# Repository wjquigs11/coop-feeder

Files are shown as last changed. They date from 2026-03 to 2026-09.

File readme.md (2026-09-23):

# Load Cell Chicken Coop Feeder Gauge

This project uses an ESP32 microcontroller connected to a load cell via an HX711 ADC to monitor the weight of a chicken feeder. The system provides a web interface with a gauge visualization showing the current feed level as a percentage. The project includes WiFi connectivity with a captive portal for easy setup, OTA updates, and a WebSerial interface for debugging and configuration.

Hanging the feeder in the coop helps to discourage pests (although rats can certainly jump up onto the feeder if they're really motivated).

# **IMPORTANT:** 

Do not build the react app on Dropbox. Compiling changes hundreds of files and Dropbox cannot sync and builds often fail. Check out the repo on a local drive for compilation.

## What It Does

- **Load Cell Monitoring**: Measures the weight of the chicken feeder using an HX711 load cell amplifier
- **Web Interface**: Displays feed level as a percentage on a gauge visualization
- **WiFi Connectivity**: Connects to your home network with easy setup via NetWizard captive portal
- **WebSerial Interface**: Provides command-line access for configuration and debugging
- **OTA Updates**: Supports over-the-air firmware updates via ElegantOTA
- **SPIFFS Storage**: Stores configuration and logs in flash memory
- **Double Reset Detection**: Reset WiFi configuration by pressing reset button twice within 10 seconds

## Hardware

- ESP32 development board (ESP32-DOIT-DEVKIT-V1) - sometimes a screw terminal board is easiest to use [Amazon Link](https://www.amazon.com/Development-Bluetooth-Microcontroller-ESP-WROOM-32-Breakout/dp/B0C8DBN29X/ref=sr_1_6)
- [HX711 load cell amplifier](https://www.sparkfun.com/products/13879)
- [Load cell (weight sensor)](https://www.sparkfun.com/products/14151)
- Power supply
- Mounting hardware for the load cell

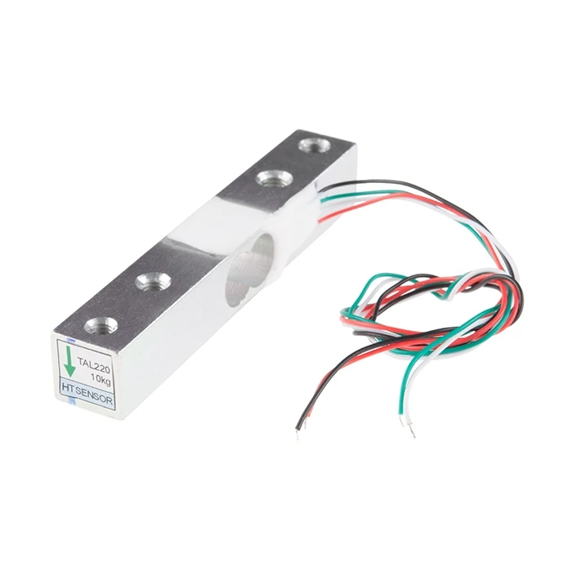
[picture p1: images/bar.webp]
bar load cell

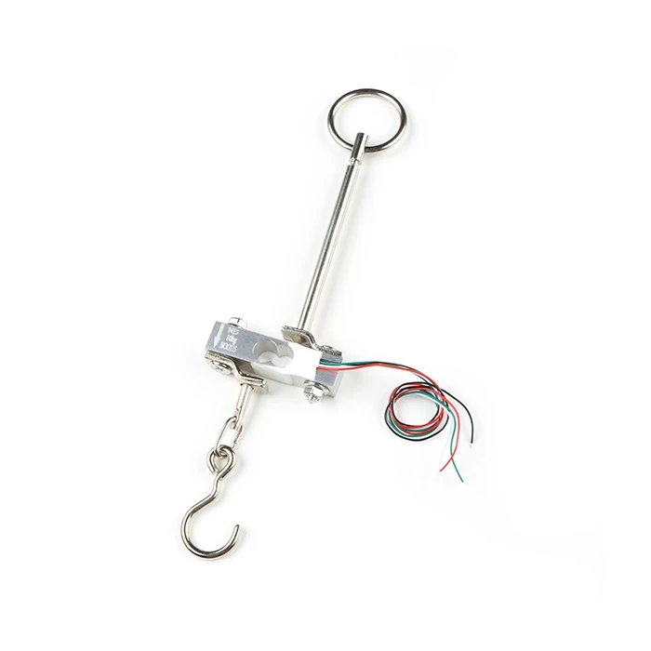
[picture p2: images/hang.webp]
hanging load cell


## Wiring

- HX711 DOUT pin → ESP32 GPIO 27
- HX711 SCK pin → ESP32 GPIO 14
- Connect load cell to HX711. [Sparkfun](https://learn.sparkfun.com/tutorials/load-cell-amplifier-hx711-breakout-hookup-guide) has a good guide.

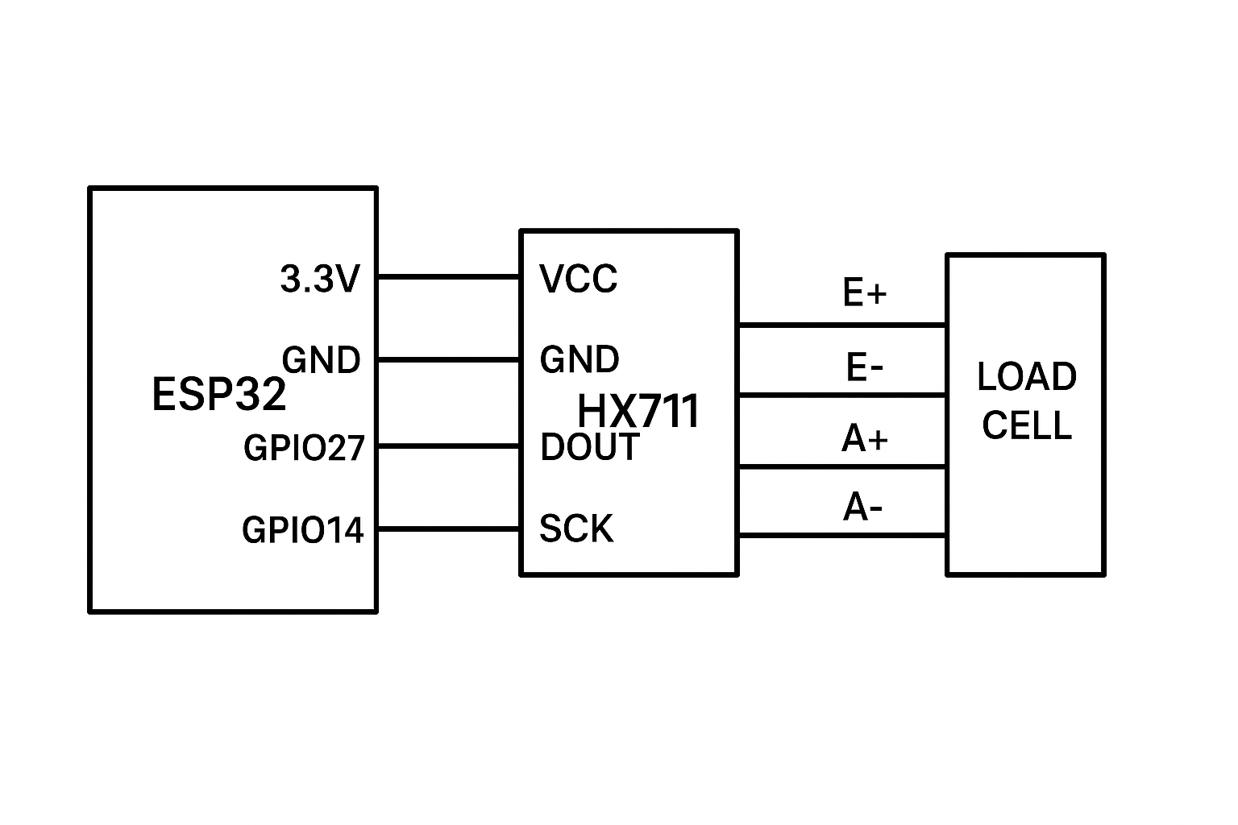
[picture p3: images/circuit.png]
circuit drawing


## Installation

1. Clone this repository
2. Open the project in [PlatformIO](https://platformio.org/)
3. Build and upload the filesystem image:
   - PlatformIO → Build Filesystem Image
   - PlatformIO → Upload Filesystem Image
     I recommend the "Pro" version of WebSerial, but if you are using the free version, modify platformio.ini to match. You will also need to change header file references.
4. Build and upload the firmware to your ESP32

- Note that the executable is fairly large; almost 4MB, so you may want to comment out definitions in platformio.ini if you don't need e.g. WebSerial. ElegantOTA is commented out but available if you modify and want to update the code without many trips to the coop :-)

## First-Time Setup

1. After the first upload, the ESP32 will start in AP mode with a NetWizard captive portal
2. Connect to the "COOPFEEDER" WiFi network from your phone or computer
3. Follow the on-screen instructions to connect the device to your home WiFi network
4. The device will restart and connect to your WiFi network
5. Place an empty feeder on the load cell
6. Calibrate the load cell with the empty feeder
   - Browse to `http://coopfeeder.local/config?empty` or
   - Use WebSerial at `http://coopfeeder.local/webserial` and enter the command `empty`
7. Fill the feeder to maximum capacity
   - Browse to `http://coopfeeder.local/config?full` or
   - Use WebSerial and enter the command `full`
     Your specific values will be saved in flash on the ESP32

  I had a bar load cell from another project. I fixed one end to a piece of flat fiberglass bar (and old sail batten), and clamped it in the coop. The feeder hangs from a split ring on the other end of the bar. The hanging-style load cell is probably easier to install.

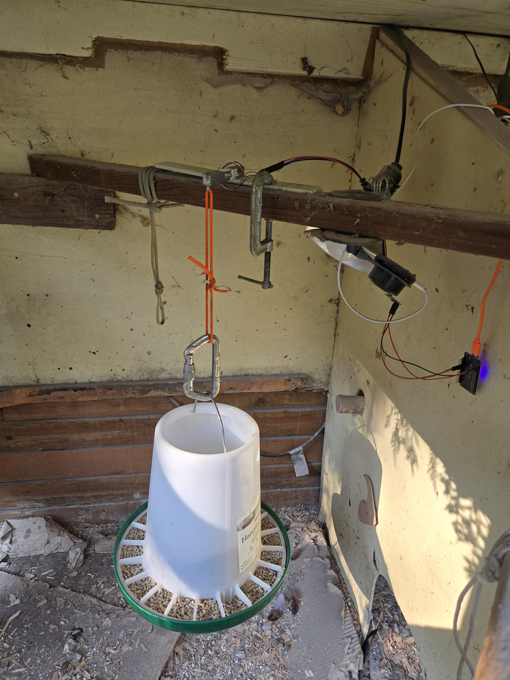
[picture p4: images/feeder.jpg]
load cell


## Web Interface

Access the web interface by navigating to `http://coopfeeder.local/` in your browser.

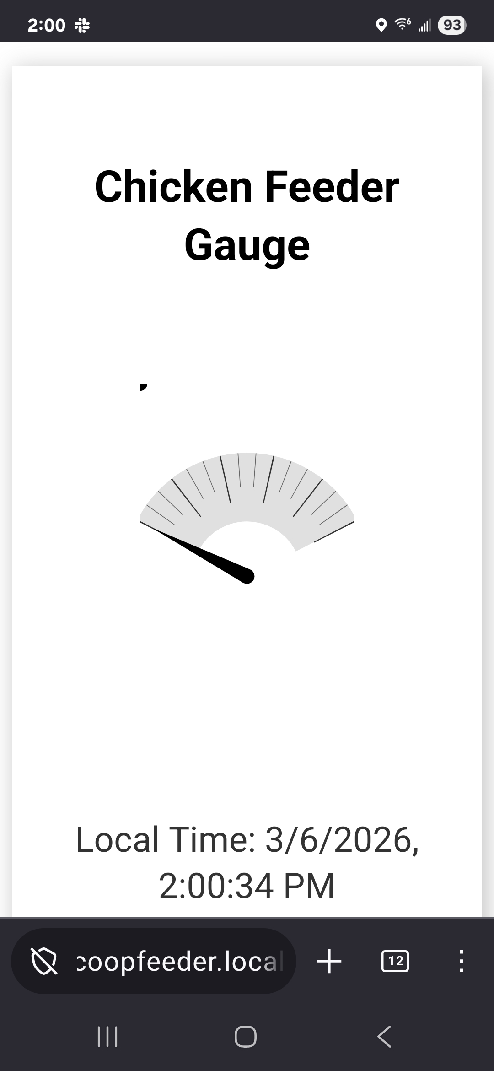
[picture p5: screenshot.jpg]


## Configuration

You can configure the device using the WebSerial interface at `http://coopfeeder.local/webserial` or by using URL parameters:

### WebSerial Commands

- `empty` - Calibrate the load cell with an empty feeder
  'empty ?' shows current raw value for empty feeder
  'empty <number></number>' sets raw value
- `full` - Calibrate the load cell with a full feeder, 'full ?' and 'full <number></number>' work same as empty.
- `hostname [name]` - Change the device hostname
- `timer [seconds]` - Change the web page update interval in seconds
- `ls` - List files in SPIFFS
- `status` - Show device status
- `wifi` - Show WiFi information
- `restart` - Restart the device
- `format` - Format the SPIFFS filesystem
- `conslog` - Restart the console log
- `log [on/off]` - Enable/disable serial logging
- `note [text]` - Add a note to the log
- `?` - Show available commands

### URL Configuration

- `http://coopfeeder.local/config?hostname=newname` - Change hostname
- `http://coopfeeder.local/config?webtimer=1000` - Change update interval (in milliseconds)
- `http://coopfeeder.local/config?empty` - Calibrate with empty feeder
- `http://coopfeeder.local/config?full` - Calibrate with full feeder

## API Endpoints

- `/readings` - Get current sensor readings as JSON
- `/weight` - Get current weight value as plain text
- `/host` - Get hostname and MAC address
- `/console.log` - Access the console log file

## Resetting WiFi Configuration

To reset the WiFi configuration and return to the captive portal setup:

1. Press the reset button on the ESP32
2. Within 10 seconds, press the reset button again
3. The device will clear WiFi settings and restart in AP mode

## Logs

A console log is stored on the SPIFFS filesystem and can be accessed via `http://coopfeeder.local/console.log`. This is mainly for debugging purposes.

## Resources

- [ESP32 Documentation](https://docs.espressif.com/projects/esp-idf/en/latest/esp32/)
- [HX711 Datasheet](https://cdn.sparkfun.com/datasheets/Sensors/ForceFlex/hx711_english.pdf)
- [PlatformIO Documentation](https://docs.platformio.org/)
- [SPIFFS Documentation](https://arduino-esp8266.readthedocs.io/en/latest/filesystem.html)

## Credits

This project depends heavily on the excellent utility libraries from [Ayush Sharma](https://github.com/ayushsharma82), as well as the lightweight Javascript gauge library from [Bernii](https://bernii.github.io/gauge.js/).

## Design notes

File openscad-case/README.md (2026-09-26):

# Hanging load-cell case with slide-in electronics

The load cell and 18650 holder stand vertically beside one another. Three paired L-shaped PCB channels are rotated 90 degrees onto the left side wall. The board planes are perpendicular to the back and lid, with populated faces toward the left wall. They grip PCB edges without mounting holes. The upper two M4 holes fix the sensor; the lower end remains free, with an M4 screw eye and a wire running over the fixed plastic guide to the bottom exit.

## Size and references

Housing: **79 mm wide × 180 mm high × 51 mm deep**, excluding screw heads and hanging loop. Overall height with loop: **205 mm**. The hanging loop is centered on the upper end of the box, at X=-7.5 and Z=24 mm (midway between back and lid). Its hole remains 10 mm diameter. The housing and lid have an oblong oval outline with 39.5 mm-radius semicircular ends; the four lid screws sit in the rounded ends. The electrical-lead slot in the side wall has been removed.

| Component | Envelope used (mm) | Source |
|---|---|---|
| Load cell | 75 × 12.7 × 12.7 | Original drawing and load-cell.png |
| Installed 18650 + holder | 78 × 21 × 21 | Assumed per user instruction, allowing holder/contact space around nominal 18 × 65 cell |
| HX711 | 33 × 20 × 6 | hx711.png footprint; assumed height |
| XIAO | 21 × 17.8 × 6 | https://wiki.seeedstudio.com/Seeeduino-XIAO/ footprint; assumed height |
| Charger | 18.2 × 12.3 × 6 | charger.png footprint including USB projection; assumed height |

PCB references assume 1.6 mm substrate thickness, 6 mm total populated height, no pin headers, and a 1.2 mm clear strip along the two retained edges. These edge/component clearances are not dimensioned in the photos: verify them on actual boards, especially soldered wires and the charger's connector. PCB envelopes depict a substrate plus an inset populated region; they are not detailed component models.

Converted AVIF copies are saved as `battery-holder.png`, `hx711.png`, `charger.png`, and `load-cell.png`. Originals remain in the folder. The holder photo has no dimension labels. Unusually long/protected cells may require a larger holder envelope.

## Printed files

- `load_cell_case.scad`: self-contained main source.
- `electronics_fit.scad`: final open-case component preview.
- `print_parts/base.stl`: case with channels, battery cradle, hanging loop, and wire guide.
- `print_parts/lid.stl`: removable lid.
The lid now has three integral board-retention stops. Separate retainers and M2 screws are no longer required.

Set `part` to `"open"` to inspect the layout. Other selections are `"assembly"`, `"exploded"`, `"base"`, `"lid"`, `"print_layout"`, `"mechanism"`, and `"cutaway"`. Assembly displays rotate upright; individual print parts are bed-oriented. Green = HX711, blue = XIAO, orange board = charger, purple = battery/holder.

## Slide channels

Each board has paired L-ledges, retaining lips, and a closed end near the back. Remove the lid and slide each board **from the lid opening toward the back**, along -Z in the part coordinates. The boards are ordered bottom to top: HX711, XIAO, charger. Their long dimensions now extend into the case depth.

- Slot height: 2.0 mm for a 1.6 mm board, with 0.2 mm clearance on either face.
- Edge fit: 0.3 mm per retained edge.
- Lip overlap: 0.8 mm onto each edge.
- Integral lid stops allow approximately 0.8 mm withdrawal before retaining the boards.
- Change `pcb_thickness` and `slot_clearance` to match actual board thickness/printer fit.

The channels attach directly to the side wall with ribs outside the PCB envelopes. No screws or adhesive touch the boards. Closing the lid installs all three retention stops; removing it releases the boards for withdrawal.

Flexible direct-soldered leads need enough slack to slide boards out. Route wires clear of the rails and lid stops. Access USB with the lid off and a board withdrawn if necessary; external USB openings are not yet defined from measured connectors and plugs. The former open side slot is closed.

## Other hardware and assembly

- Two M4×10 socket-head screws for the fixed upper sensor end, nominally 6.2 mm engagement. Verify thread depth.
- One purchased M4 eye for the upper hole of the lower pair. Reference: 8 mm outside eye diameter, 5 mm opening, 2.5 mm eye thickness, 4 mm nominal thread engagement.
- Four M3×50 socket-head screws and four M3 nuts for the lid.
- Two small cable ties for the battery holder through the rear slots at Y=12 and Y=60.

The raised battery bed and side rails locate the holder. The load cell mounts at X=-12, with inferred hole positions Y=5.5, 15.5, 59.5, and 69.5. Part axes: X across, Y upward when hanging, Z outward from the back. Confirm the inferred 5.5 mm end margin on the sensor.

Print the case back-down with supports under the curved wire guide and the relocated hanging loop, which now starts 21 mm above the print bed. Inspect the side-channel overhangs in the slicer and keep support material out of the 2 mm grooves. Print the lid exterior-down with its three retention stops pointing upward. PETG and 4–5 walls are prototype starting settings. Clear grooves and smooth the wire-contact surface before assembly.

## Validation and limits

OpenSCAD MCP mesh checks found single watertight, manifold solids for the case and lid. All 21 assembly-pair checks for the revised oval base, lid, battery, sensor, and three boards passed, with 0.8 mm between each board and its lid stop. Earlier sampled sliding-motion checks passed for all three PCBs with the lid removed, against the case, sensor, and battery; that motion sweep has not been repeated for the oval revision. Minimum modeled groove clearance was 0.2 mm. Printed fit still needs checking.

The battery envelope clears the sensor by 9.65 mm. The components retain free space above and around the sensor; the guide remains 6 mm from the sensor. Loaded deflection, actual wires, knots/crimps, plugs, solder joints and printed strength are not validated by these envelope checks.

The fixed guide takes some of the external load; friction and wire bending can cause hysteresis. Calibrate the complete hanging assembly with its actual wire. No overload stop, environmental seal, or load rating is claimed.

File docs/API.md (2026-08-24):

# Coop Feeder HTTP API

This document describes the HTTP endpoints exposed by the coop feeder's
ESP32 web server that an external client (for example a phone app) can use to
read feeder state and change configuration. It is intended for clients that are
not the built-in browser UI.

## Base URL

The device serves HTTP on port `80`. Reach it by IP address or by mDNS
hostname:

```
http://<device-ip>/
http://coopfeeder.local/          # default mDNS name (hostname is configurable)
```

- The mDNS name is derived from the configured hostname (see `/config`), lower
  cased and sanitized to `a-z`, `0-9` and `-`. The default hostname is
  `coopfeederBETA`.
- In AP (access point) mode the device is reachable at its soft-AP IP instead.

## CORS

`GET` endpoints send permissive CORS headers (`Access-Control-Allow-Origin: *`),
and `OPTIONS` preflight requests are answered with `204`. A native phone app
making direct HTTP calls does not need CORS, but a browser-based or hybrid app
will work cross-origin.

---

## Getting feeder state

### GET `/readings`

Primary endpoint for reading current feeder state. Returns the full state
object as JSON.

**Response** `200 application/json`

```json
{
  "loadcell": "72",
  "units": "%",
  "lastUpdate": "1740000000000"
}
```

| Field | Type | Description |
|---|---|---|
| `loadcell` | string (integer)  | Current feed level, `0`–`100`. Mapped from the raw load cell reading between the empty and full calibration offsets. |
| `units` | string | Unit for `loadcell`. Currently `"%"`. |
| `lastUpdate` | string (integer)  | Timestamp of the last reading, in **milliseconds since the Unix epoch**. See note below. |

Notes:
- All values are serialized as JSON **strings**, not numbers. Parse them
  client-side (e.g. `parseInt`).
- Fields only appear once the device has taken at least one reading. Before the
  first reading the object may be empty (`{}`).
- `lastUpdate` is only a true Unix timestamp if a client has posted the current
  time via `POST /browsertime` (see below). The ESP32 has no real-time clock, so
  until then it falls back to the device uptime (`millis()`), which is **not** a
  wall-clock time.

### GET `/weight`

Lightweight endpoint returning just the current feed level as plain text.

**Response** `200 text/plain`

```
72
```

The value is the same `loadcell` figure (`0`–`100`) returned by `/readings`,
without units or timestamp. Useful for a quick poll when you only need the level.

### GET `/host`

Returns device identity information as human-readable plain text (not JSON).

**Response** `200 text/plain`

```
hostname: coopfeederBETA, ESP local MAC addr: AA:BB:CC:DD:EE:FF
```

Contains the current hostname and the ESP32's Wi-Fi MAC address. Handy for
device discovery / identification. The format is a plain string, so parse it
loosely.

---

## Live updates (Server-Sent Events)

### GET `/events`

A Server-Sent Events (SSE) stream. Instead of polling `/readings`, a client can
subscribe once and receive pushes whenever the device takes a new reading.

- Event name: `new_readings`
- Event data: the same JSON payload as `GET /readings`
- On connect, the device immediately sends one `new_readings` event so the
  client is populated right away.
- The push cadence is governed by the device's timer delay (see the `webtimer`
  parameter of `/config`).

Example (browser `EventSource`):

```js
const es = new EventSource("http://coopfeeder.local/events");
es.addEventListener("new_readings", (e) => {
  const state = JSON.parse(e.data);
  console.log(state.loadcell, state.units, state.lastUpdate);
});
```

For a native phone app, use any SSE-capable HTTP client, or fall back to polling
`/readings` on an interval if SSE is inconvenient.

---

## Configuration and calibration

### GET `/config`

Changes device settings. Despite modifying state, it uses `GET` with query
parameters. Send exactly one parameter per request; the first recognized one is
applied. Returns a plain-text confirmation message.

**Response** `200 text/plain` (e.g. `"change web timer to 2000"`, or `"none"`
if no recognized parameter was supplied).

| Parameter  | Example | Effect |
|---|---|---|
| `hostname` | `/config?hostname=henhouse` | Sets the device hostname (also affects the mDNS name). Persisted to flash. |
| `webtimer` | `/config?webtimer=2000` | Sets the reading/update interval in **milliseconds**. Clamped to `0`–`10000`; `<0` resets to the default (`1000`). Persisted. |
| `empty` | `/config?empty=1` | Runs the "empty feeder" calibration (captures the current raw load cell reading as the empty offset). Persisted. |
| `full` | `/config?full=1` | Runs the "full feeder" calibration (averages several raw readings as the full offset). Persisted. |

The `empty` / `full` parameter values are ignored — only presence matters.
Confirmation messages include the resulting offset values, for example
`"empty calibration successful, empty raw offset is 12345"`.

### POST `/browsertime`

Supplies the device with a wall-clock time reference so that `lastUpdate` in
`/readings` becomes a real Unix timestamp. The ESP32 has no RTC, so a client
should send this once after connecting (and periodically if desired).

**Request body** `application/json`

```json
{
  "localTime": "2026-08-24T10:00:00",
  "timezone": "America/New_York",
  "offset": -240,
  "timestamp": 1740000000000
}
```

| Field | Type | Description |
|---|---|---|
| `timestamp` | number | Current time in **milliseconds since the Unix epoch**. This is the value the device actually uses as its clock base. |
| `localTime` | string | Human-readable local time (logged only). |
| `timezone`  | string | IANA timezone name (logged only). |
| `offset` | number | UTC offset in minutes (logged only). |

**Response** `200 text/plain` — body `"Time received"`.

Only `timestamp` affects behavior; the other fields are logged for diagnostics.

---

## Endpoint summary

| Method | Path | Response type | Purpose |
|---|---|---|---|
| GET | `/readings` | `application/json` | Full feeder state (level, units, time) |
| GET | `/weight` | `text/plain` | Current feed level only (`0`–`100`) |
| GET | `/host` | `text/plain` | Hostname + MAC address |
| GET | `/events` | SSE stream | Push updates (`new_readings` events) |
| GET | `/config` | `text/plain` | Change hostname / timer / run calibration |
| POST | `/browsertime` | `text/plain` | Provide a wall-clock time reference |

## Recommended client flow

1. Discover the device (mDNS `coopfeeder.local` or a known IP).
2. Optionally `GET /host` to confirm identity (MAC address).
3. `POST /browsertime` with the current epoch milliseconds so `lastUpdate`
   reflects real time.
4. Either subscribe to `GET /events` for live `new_readings`, or poll
   `GET /readings` (or `GET /weight`) on an interval.
5. Use `GET /config` as needed to adjust the update interval or run calibration.

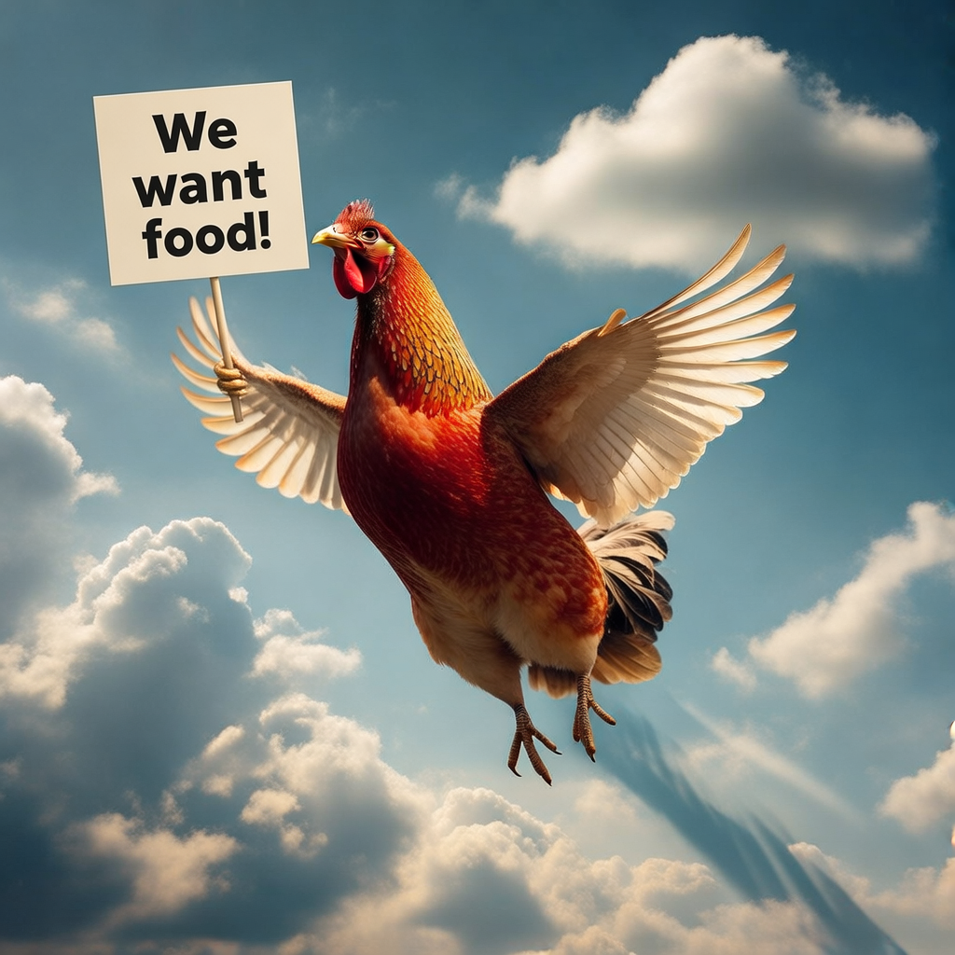
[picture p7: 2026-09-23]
react-app/assets/images/superchicken.png

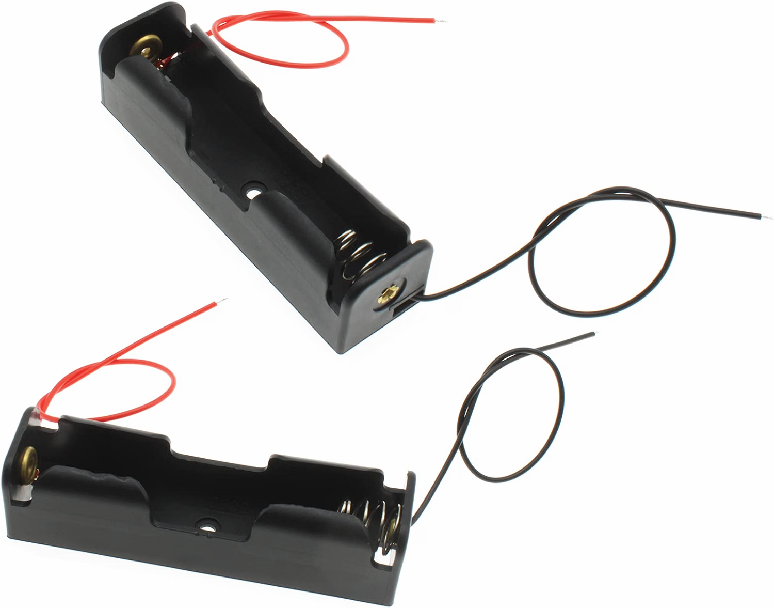
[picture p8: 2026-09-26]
openscad-case/battery-holder.png

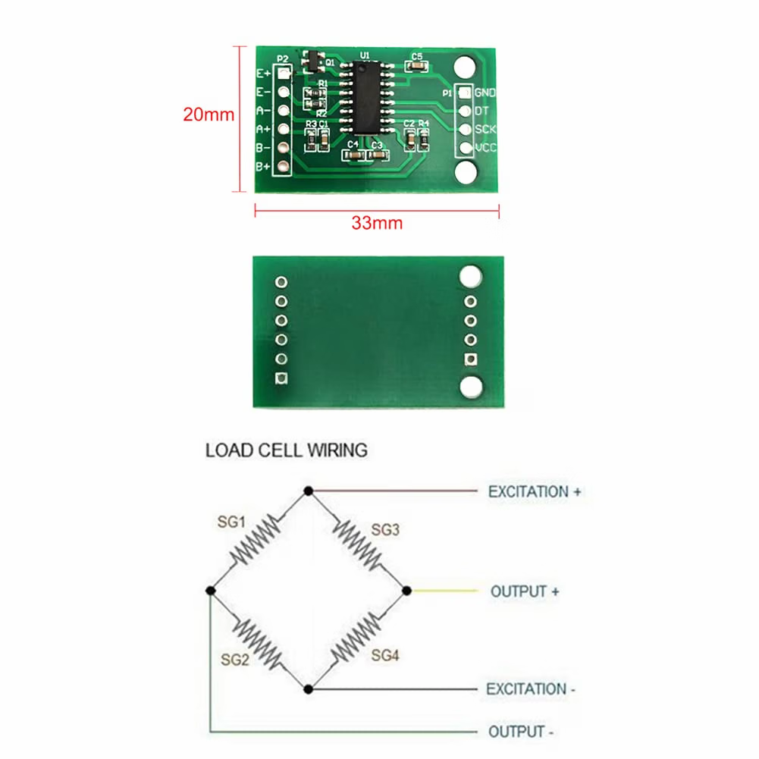
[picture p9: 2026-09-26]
openscad-case/hx711.png

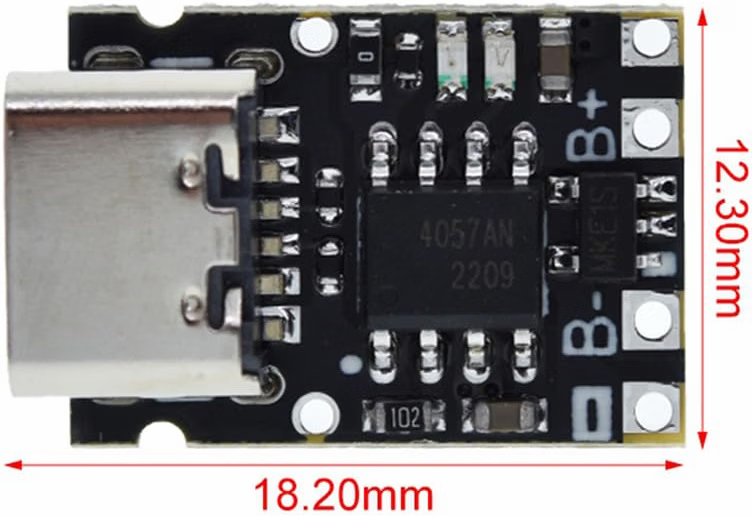
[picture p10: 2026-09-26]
openscad-case/charger.png

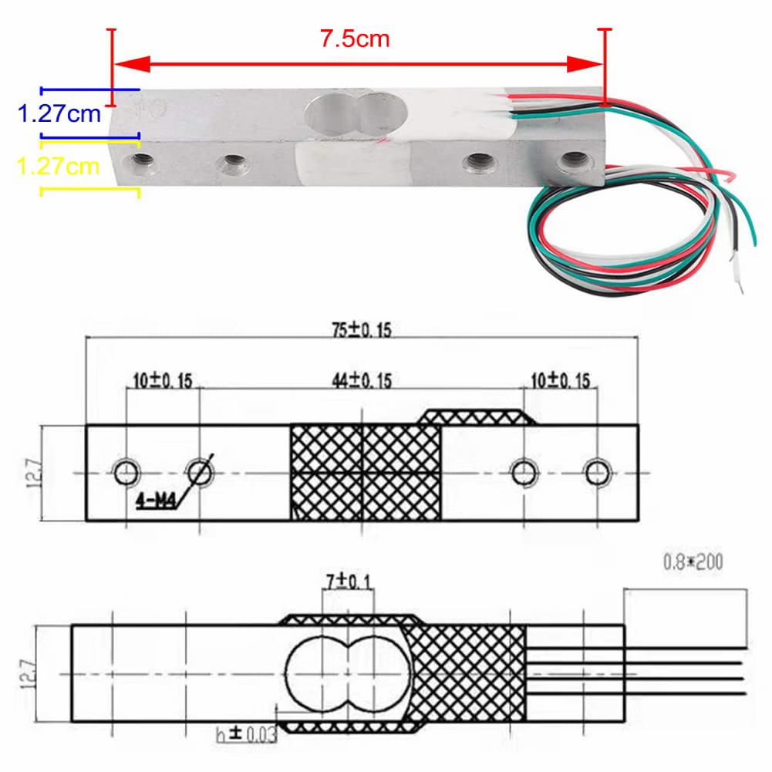
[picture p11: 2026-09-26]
openscad-case/load-cell.png

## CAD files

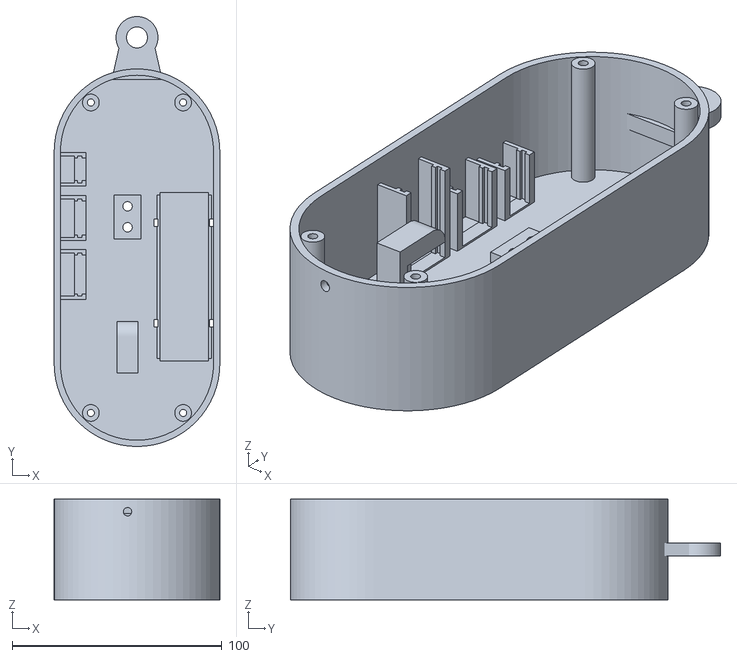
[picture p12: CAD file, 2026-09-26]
openscad-case/print_parts/base.stl
79.0 x 205.0 x 48.0

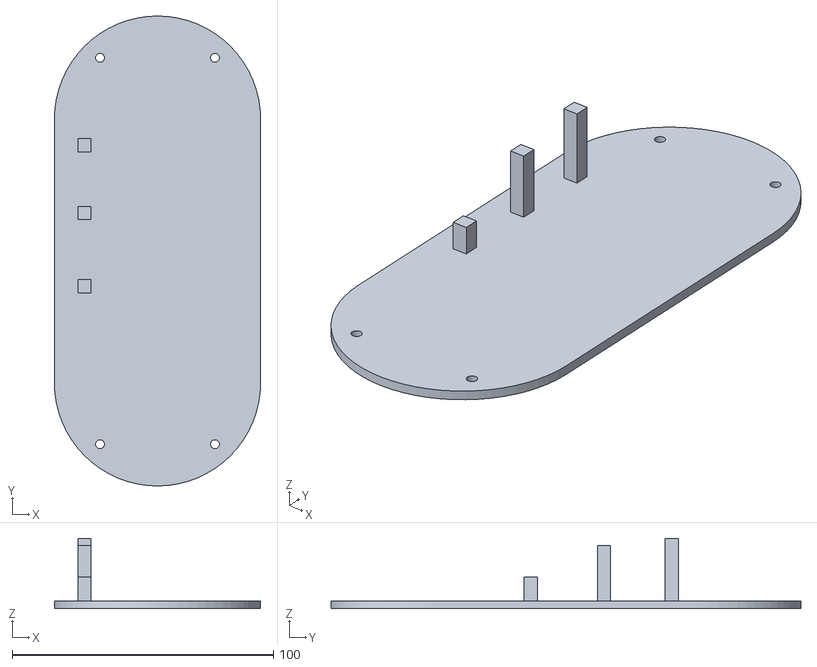
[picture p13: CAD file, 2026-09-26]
openscad-case/print_parts/lid.stl
79.0 x 180.0 x 27.0

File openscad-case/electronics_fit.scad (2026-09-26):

// Final enlarged case, with vertical battery alongside the sensor.
// Component envelopes are defined in load_cell_case.scad.
// Purple: assumed 78 x 21 x 21 holder/battery; green: HX711;
// blue: XIAO; orange: charger. All PCB heights assumed 6 mm.
use <load_cell_case.scad>
rotate([90,0,0]) open_case();

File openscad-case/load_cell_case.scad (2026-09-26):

// Vertical hanging case, revised from case.jpg. Units mm.
// Print coordinates: X across case, Y up when hanging, Z out from back.
// Sensor upper end is fixed. Hole axes are Z; sketch is a side view.
part="assembly"; // assembly, open, exploded, base, lid, print_layout, mechanism, cutaway
show_reference=true;
show_electronics=true;
$fn=64;
cell_l=75; cell_w=12.7; cell_h=12.7;
cell_z=8; holes_y=[69.5,59.5,15.5,5.5];
case_left=-47; case_right=32; case_w=case_right-case_left;
case_mid=(case_left+case_right)/2;
cell_x=case_mid; // load-cell holes and wire diverter centered left/right in case
bottom_y=-45; top_y=135; case_depth=38; // thinned 10mm in Z (was 48)
wall=3; floor_h=4; lid_h=3;
// Sealing rim: thicken the perimeter wall to rim_wall over the top rim_h of depth,
// and cut a gasket groove into the top mating face.
rim_wall=8; rim_h=8;              // thickened wall and its depth band below the top face
groove_off=3; groove_w=3; groove_d=3; // groove: 3mm from outer edge, 3mm wide, 3mm deep
wire_d=1.6; wire_hole_d=4;
guide_r=7.2; guide_y=7.5; guide_z=24; // strut thinned 10mm in Z with the case (was 34)
wire_r=guide_r+wire_d/2;
guide_w=10; // guide body width along X
guide_flange_t=1.5; // side flange thickness (X)
guide_flange_h=wire_d+1.5; // flange rise above wire crown (Z)
eye_od=8; eye_id=5; eye_z=27; eye_y=15.5;
// Screw posts pulled inward so the M3 holes clear the gasket groove by ~2mm.
screw_dx=20.15; screw_iy=17.58; // X half-spread from center; Y inset from each end
screws=[for(y=[bottom_y+screw_iy,top_y-screw_iy],x=[case_mid-screw_dx,case_mid+screw_dx]) [x,y]];
battery_l=78; battery_w=21; battery_h=21; // Assumed holder + installed cell.
battery_pos=[7.8,-3,6]; // centered in pocket: left rail inner face x=7.6, case inner wall x=29, 0.4mm clearance
pcb_h=6; // Total populated height; direct solder, no pin headers.
pcb_z=32; pcb_thickness=1.6; slot_clearance=0.4;
hx_pos=[-42,27,pcb_z]; hx_size=[25,16,pcb_h]; // board 24mm deep + 1mm clearance
xiao_pos=[-42,55,pcb_z]; xiao_size=[21,17.8,pcb_h];
charger_pos=[-42,81,pcb_z]; charger_size=[18.2,12.3,pcb_h];
boards=[[hx_pos,hx_size],[xiao_pos,xiao_size],[charger_pos,charger_size]];
rail_seat=pcb_z-slot_clearance/2; rail_bottom=rail_seat-2;
rail_lip=pcb_z+pcb_thickness+slot_clearance/2; rail_top=rail_lip+1.6;
eps=0.02;
assert(wire_d<wire_hole_d,"Wire must clear exit");
assert(guide_z+wire_r+wire_d/2<case_depth,"Wire must clear lid");
module rounded_box(w,h,d,r=3) {
 linear_extrude(d) hull() for(x=[r,w-r],y=[r,h-r]) translate([x,y]) circle(r=r);
}
module case_outline(inset=0) {
 // Oblong oval: semicircular ends and straight sides preserve the electronics bay.
 translate([case_mid,0]) hull()
  for(y=[bottom_y+case_w/2,top_y-case_w/2])
   translate([0,y]) circle(r=case_w/2-inset);
}
module yz_extrude(w) {
 // child 2D coordinates [Y,Z], extruded along X
 multmatrix([[0,0,1,-w/2],[1,0,0,0],[0,1,0,0],[0,0,0,1]]) linear_extrude(w) children();
}
module guide_local() {
 // Integral fixed shoe: quarter-circle crown, vertical stem, and back attachment.
 yz_extrude(guide_w) union() {
  translate([-10,floor_h-eps]) square([4,guide_z+guide_r-floor_h+eps]);
  translate([-9,guide_z]) square([guide_y+9,guide_r]);
  translate([guide_y,guide_z]) intersection() {
   circle(r=guide_r);
   square([guide_r,guide_r]);
  }
 }
 // Side flanges: raised walls on both X faces to keep the wire from slipping off
 // the crown sideways. Span the crown in Y and rise in Z past the wire.
 for(sx=[-1,1])
  translate([sx*(guide_w/2)+(sx<0?-guide_flange_t:0),-9,guide_z])
   cube([guide_flange_t,guide_y+9+guide_r,wire_r+guide_flange_h]);
}
module guide() { translate([cell_x,0,0]) guide_local(); }
module hanger() {
 // Centered across the box and halfway between back and lid on upper end.
 translate([0,0,case_depth/2-3]) linear_extrude(6) difference() {
  union() {
   polygon([[case_mid-12,top_y-5],[case_mid+12,top_y-5],[case_mid+7,top_y+17],[case_mid-7,top_y+17]]);
   translate([case_mid,top_y+15]) circle(d=20);
  }
  translate([case_mid,top_y+15]) circle(d=10);
 }
}
module base() {
 difference() {
  union() {
   difference() {
    linear_extrude(case_depth) case_outline();
    translate([0,0,floor_h])
     linear_extrude(case_depth+eps) case_outline(wall);
   }
   // Sealing rim: thicken the perimeter wall from wall to rim_wall over the top rim_h,
   // added inward (outer footprint unchanged) to carry the gasket groove.
   translate([0,0,case_depth-rim_h]) linear_extrude(rim_h+eps) difference() {
    case_outline(wall);
    case_outline(rim_wall);
   }
   // Pedestal touches only upper 21 mm of beam.
   translate([cell_x-cell_w/2,54,floor_h-eps]) cube([cell_w,21,cell_z-floor_h+eps]);
   // Battery bed and low side rail.
   // L-shape: only the left rail; the case wall is the right side.
   // Battery (battery_w=21) fits between left rail inner face (x=7.6) and case inner wall
   // (x=case_right-wall=29): 21.4mm pocket = 0.4mm total clearance for print tolerance.
   translate([6.1,-4.2,floor_h-eps]) cube([22.9,80.2,2+eps]);
   for(x=[6.1]) translate([x,-3,floor_h-eps]) cube([1.5,78,6+eps]);
   for(p=screws) translate([p[0],p[1],0]) cylinder(h=case_depth,r=4);
   hanger(); guide();
   for(b=boards) {
    board_frame() pcb_channel(b[0],b[1]);
    // Join both channel sides to the left wall, outside the board envelope.
    for(y=[b[0][1]-1.9,b[0][1]+b[1][1]+0.3])
     translate([case_left+wall-eps,y,floor_h-eps])
      cube([6.8+eps,1.6,b[0][0]+b[1][0]+47.3-floor_h+eps]);
   }
  }
  for(y=[holes_y[0],holes_y[1]]) {
   translate([cell_x,y,-eps]) cylinder(h=cell_z+2*eps,d=4.5);
   translate([cell_x,y,-eps]) cylinder(h=4.2+eps,d=8);
  }
  // M3 lid screws into captive nuts accessible from the back.
  for(p=screws) {
   translate([p[0],p[1],-eps]) cylinder(h=case_depth+2*eps,d=3.4);
   translate([p[0],p[1],-eps]) rotate([0,0,30]) cylinder(h=2.7+eps,d=5.8/cos(30),$fn=6);
  }
  // Load wire exits through bottom, tangent to guide.
  translate([cell_x,bottom_y-eps,guide_z+wire_r]) rotate([-90,0,0]) cylinder(h=wall+3,d=wire_hole_d);
  // Gasket groove in the top mating face: 3mm from outer edge, 3mm wide, 3mm deep.
  translate([0,0,case_depth-groove_d]) linear_extrude(groove_d+eps) difference() {
   case_outline(groove_off);
   case_outline(groove_off+groove_w);
  }
 }
}
module lid() {
 // Print exterior face down.
 difference() {
  union(){
   linear_extrude(lid_h) case_outline();
   // Lid-mounted stops retain the side-loading boards with 0.8 mm end play.
   // Disabled per request; retained for reference.
   // for(b=boards)
   //  translate([-38,b[0][1]+2,lid_h-eps])
   //   cube([5,5,case_depth-(b[0][0]+b[1][0]+47+0.8)+eps]);
  }
  for(p=screws) {
   translate([p[0],p[1],-eps]) cylinder(h=lid_h+2*eps,d=3.4);
   // 1 mm head recess gives a 50 mm grip to underside nuts.
   translate([p[0],p[1],-eps]) cylinder(h=1+eps,d=6.4);
  }
 }
}
module sensor_local() {
 difference() {
  union() {
   translate([-cell_w/2,0,cell_z]) cube([cell_w,cell_l,cell_h]);
   // Undimensioned coating: provisional 0.5 mm allowance.
   translate([-cell_w/2-0.5,26,cell_z-0.5]) cube([cell_w+1,22,cell_h+1]);
  }
  for(y=holes_y) translate([0,y,cell_z-eps]) cylinder(h=cell_h+2*eps,d=4);
 }
}
module sensor(){translate([cell_x,0,0]) sensor_local();}
module screw_eye_local() {
 // Illustrative purchased M4 eye: replace dimensions with actual hardware.
 translate([0,eye_y,cell_z+cell_h-4]) cylinder(h=eye_z-eye_od/2-(cell_z+cell_h-4)+0.5,d=4);
 translate([0,eye_y,eye_z]) rotate([0,90,0]) difference() {
  cylinder(h=2.5,d=eye_od,center=true);
  cylinder(h=3,d=eye_id,center=true);
 }
}
module screw_eye(){translate([cell_x,0,0]) screw_eye_local();}
module wire_segment(a,b) { hull() { translate(a) sphere(d=wire_d); translate(b) sphere(d=wire_d); } }
module wire_local() {
 // Schematic attachment at outer eye; knot/crimp not represented.
 wire_segment([0,eye_y,eye_z+eye_od/2],[0,guide_y+wire_r,guide_z]);
 for(a=[0:5:85]) wire_segment(
  [0,guide_y+wire_r*cos(a),guide_z+wire_r*sin(a)],
  [0,guide_y+wire_r*cos(a+5),guide_z+wire_r*sin(a+5)]);
 wire_segment([0,guide_y,guide_z+wire_r],[0,bottom_y-15,guide_z+wire_r]);
}
module wire(){translate([cell_x,0,0]) wire_local();}
module battery(){translate(battery_pos) cube([battery_w,battery_l,battery_h]);}
module pcb_reference(p,s){
 // Substrate plus inset populated envelope: assumes 1.2mm clear long edges.
 translate(p) {
  cube([s[0],s[1],pcb_thickness]);
  translate([0,1.2,pcb_thickness]) cube([s[0],s[1]-2.4,s[2]-pcb_thickness]);
 }
}
// Rotate board planes 90 degrees onto the left side; insertion is along -Z.
// Old X maps to depth; populated faces point toward the left wall.
module board_frame(){translate([-2,0,47]) rotate([0,-90,0]) children();}
module hx711(){board_frame() pcb_reference(hx_pos,hx_size);}
module xiao(){board_frame() pcb_reference(xiao_pos,xiao_size);}
module charger(){board_frame() pcb_reference(charger_pos,charger_size);}
module pcb_channel(p,s){
 start=case_left+wall-1; end=p[0]+s[0]+0.3;
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

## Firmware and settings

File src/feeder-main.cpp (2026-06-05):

/*
Basic chicken coop feeder weight monitor based on ESP32
Uses a load cell and HX711 ADC
To use, first go to PlatformIO->Build Filesystem Image, then Upload Filesystem Image, then build and upload to your ESP32
At first upload, it will start the NetWizard captive portal to scan and select wifi
After reboot, it will connect to your wifi
To reset wifi connection (go back to captive portal), press reset on the ESP32 twice within 10 seconds (double reset detector)
Usage:
First, put an empty feeder on the load cell, then tare the load cell
There are several ways to tare:
  Either browse to "http://coopfeeder.local/config?tare"
  or use "http://coopfeeder.local/webserial", which is a basic command-line interface, and enter "tare"
  or click the "calibrate empty" button on the web interface
You can also change the hostname and the response time for the web interface (default 1 second) using /config
A console log is stored on LittleFS; access it via http://coopfeeder.local/console.log
This repo uses the WebSerial and NetWizard libraries from ayusharma, as well as the ElegantOTA library for development
*/

#include "include.h"

File consLog;
Preferences preferences;

bool wifiEnabled = false;
int timerDelay = 1000;
unsigned long lastTime = 0;

// Deferred flash write state
volatile bool pendingSaveToPrefs = false;
volatile bool pendingHostnameChange = false;
String pendingHostname = "";
volatile bool pendingTimerChange = false;
int pendingTimerDelay = 0;

// HX711 circuit wiring
const int HX711_dout = 27; //mcu > HX711 dout pin
const int HX711_sck = 14; //mcu > HX711 sck pin
HX711 LoadCell;

unsigned long t = 0;
float calibrationValue=1.0; // calibration value (see example file "Calibration.ino")
long loadcell=0;
long empty_offset = 0; // offset value for empty feeder
long full_raw = -420000; // offset value for full feeder (remember it's in tension so "reverse")

// Configure tare offset values, calculate and save to preferences:
void configTare(const String& type) {
  log::toAll("Calculating " + type + " offset value...");
  if (type == "empty") {
    empty_offset = LoadCell.read();
    preferences.putLong("empty_offset", empty_offset);
    log::toAll("New empty offset value: " + String(empty_offset));
  } else if (type == "full") {
    static long totalRaw = 0;
    int i = 0;
    while (i<10) {
      // take 10 samples
      if (LoadCell.is_ready()) {
        long raw = LoadCell.read();   
        log::toAll("raw[" + String(i) + "]: " + String(raw));
        totalRaw += raw;
        i++;
        delay(10);
      }
    }
    full_raw = totalRaw / 10.0;
    preferences.putLong("full_raw", full_raw);
    log::toAll("total: " + String(totalRaw) + ", New full offset value: " + String(full_raw));
  }
}

void setup() {
  Serial.begin(115200); delay(300);
  //pinMode(HX711_dout, INPUT);
  //pinMode(HX711_sck, OUTPUT);

  if (LittleFS.begin(true))
    Serial.println("opened LittleFS");
  else
    Serial.println("failed to open LittleFS");

  log::initConsole();
  preferences.begin("ESPprefs", false);
  //restore the offset values from preferences:
  empty_offset = preferences.getLong("empty_offset", 0);
  full_raw = preferences.getLong("full_raw", 0);
  log::toAll("loaded empty offset value " + String(empty_offset));
  log::toAll("loaded full offset value " + String(full_raw));
  timerDelay = preferences.getInt("timerdelay", 10000);
  if (timerDelay<200) {
    timerDelay = 200;
    preferences.putInt("timerdelay", 1000);
  }
  log::toAll("timerDelay " + String(timerDelay));
#ifdef WIFI
  host = preferences.getString("hostname", host);
  log::toAll("hostname: " + host);
#endif
  wifiEnabled = preferences.getBool("wifi", true);

  // start the load cell
  LoadCell.begin(HX711_dout,HX711_sck);

#ifdef WIFI
  bool doubleReset = preferences.getBool("DRD", false);

  if (wifiEnabled) {
    if (doubleReset) {
      // DRD currently not working without Netwizard
      log::toAll("double reset detected");
      //resetWifi();
      //NW.erase();
      preferences.putBool("DRD", false);
      //ESP.restart();
    }
    //} else {
      preferences.putBool("DRD", true);
      bool wifiConnected = setupWifi();
      // Start the web server regardless of WiFi connection status
      // In fallback mode, it will serve from AP mode
      startWebServer();
      
#ifdef ELEGANTOTA
      ElegantOTA.begin(&server);
#endif
#ifdef WEBSERIAL
      WebSerial.begin(&server);
      // Attach a callback function to handle incoming messages
      WebSerial.onMessage(WebSerialonMessage);
#endif
      serverStarted = true;
      
      if (wifiConnected) {
        log::toAll("HTTP server started @" + WiFi.localIP().toString());
      } else {
        log::toAll("HTTP server started in AP mode @" + WiFi.softAPIP().toString());
      }
      // Sanitize hostname for mDNS
      String mdnsHost = host;
      mdnsHost.toLowerCase();
      mdnsHost.replace("_", "-");
      mdnsHost.replace(" ", "-");
      String sanitized = "";
      for (int i = 0; i < (int)mdnsHost.length() && i < 63; i++) {
        char c = mdnsHost.charAt(i);
        if ((c >= 'a' && c <= 'z') || (c >= '0' && c <= '9') || c == '-') {
          sanitized += c;
        }
      }
      if (sanitized.length() > 0) {
        if (!MDNS.begin(sanitized.c_str())) {
          log::toAll("Error starting MDNS responder");
        } else {
          snprintf(logbuf, LOGBUF_SIZE, "MDNS started as %s.local", sanitized.c_str());
          log::toAll(logbuf);
        }
      } else {
        log::toAll("Invalid hostname for MDNS");
      }
      // Add service to MDNS-SD
      if (!MDNS.addService("http", "tcp", HTTP_PORT))
        log::toAll("MDNS add service failed");
    //}
  }
#endif // WIFI
  log::flush();
} // setup()

void loop() {
#ifdef ELEGANTOTA
  ElegantOTA.loop();
#endif
#ifdef WEBSERIAL
  WebSerial.loop();
#endif
#ifdef NETWIZARD
  NW.loop();
#endif
  unsigned long now = millis();
  static unsigned long lastEventTime, lastTimeTime, startTime;
#ifdef WIFI
  wifiCheck();
  // update web page
  static bool drdCleared = false;
  
  // Clear DRD flag after DRD_TIMEOUT seconds for double reset detection
  // unless reset occurs within the timeout period
  if (!drdCleared && (now > (DRD_TIMEOUT * 1000))) {
    preferences.putBool("DRD", false);
    drdCleared = true;
    log::toAll("DRD timeout - cleared double reset flag");
  }
#endif
  if (now - lastEventTime > timerDelay || lastEventTime == 0) {
    lastEventTime = now;
    // check load cell
    static boolean newDataReady = 0;
    // check for new data/start next conversion:
    if (LoadCell.is_ready()) {
      newDataReady = true;
    }
    if (newDataReady) {
      long raw = LoadCell.read();
      loadcell = map(raw, empty_offset, full_raw, 0, 100);
      if (loadcell > 100) loadcell = 100;
      if (loadcell < 0) loadcell = 0;
      newDataReady = false;
      log::toAll("[" + String(now) + "] raw: " + String(raw) + " scaled: " + String(loadcell));
#if WIFI
      readings["loadcell"] = String(loadcell);
      readings["units"] = "%";
      
      // Calculate current time based on browser timestamp plus elapsed time
      if (updateTime > 0) {
        // Use the browser's timestamp as base and add elapsed milliseconds
        // This gives us a proper Unix timestamp in milliseconds
        lastUpdate = updateTime + (now - lastEventTime);
      } else {
        // If updateTime is not set yet, use the current time as a fallback
        // But this will be incorrect since ESP32 millis() is not a Unix timestamp
        lastUpdate = now;
      }
      
      // Send the timestamp in milliseconds since epoch (Unix timestamp)
      readings["lastUpdate"] = String(lastUpdate);
      
      events.send(getSensorReadings().c_str(),"new_readings" ,millis());
#endif
    }
  }
  // Serial/WebSerial command handler
#ifdef WEBSERIAL
  pollSerialConsole();
#endif
  // Deferred flash writes — do them here, not from async web handlers
  if (pendingSaveToPrefs) {
    pendingSaveToPrefs = false;
    if (pendingHostnameChange) {
      pendingHostnameChange = false;
      preferences.putString("hostname", pendingHostname);
      log::toAll("preferences saved hostname: " + pendingHostname);
    }
    if (pendingTimerChange) {
      pendingTimerChange = false;
      preferences.putInt("timerdelay", pendingTimerDelay);
      snprintf(logbuf, LOGBUF_SIZE, "preferences saved timerdelay: %d", pendingTimerDelay);
      log::toAll(logbuf);
    }
  }
  log::flush();
} // loop()

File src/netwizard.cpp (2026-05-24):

#ifdef NETWIZARD
#include "include.h"

#if defined(ESP32)
//  #include <AsyncTCP.h>
#elif defined(TARGET_RP2040) || defined(TARGET_RP2350) || defined(PICO_RP2040) || defined(PICO_RP2350)
  #include <RPAsyncTCP.h>
#endif

// Initialize NetWizard
NetWizard NW(&server);

// Setup configuration parameters
//NetWizardParameter nw_header(&NW, NW_HEADER, "MQTT");
//NetWizardParameter nw_divider1(&NW, NW_DIVIDER);

bool setupWifi(void) {
  Serial.println("Starting wifi...");

  // ----------------------------
  // Configure NetWizard Strategy
  // ----------------------------
  // BLOCKING - Connect to WiFi and wait till portal is active
  // (blocks execution after autoConnect)
  // 
  // NON_BLOCKING - Connect to WiFi and proceed while portal is active in background
  // (does not block execution after autoConnect)
  NW.setStrategy(NetWizardStrategy::BLOCKING);

  // Listen for connection status changes
  NW.onConnectionStatus([](NetWizardConnectionStatus status) {
    String status_str = "";

    switch (status) {
      case NetWizardConnectionStatus::DISCONNECTED:
        status_str = "Disconnected";
        break;
      case NetWizardConnectionStatus::CONNECTING:
        status_str = "Connecting";
        break;
      case NetWizardConnectionStatus::CONNECTED:
        status_str = "Connected";
        break;
      case NetWizardConnectionStatus::CONNECTION_FAILED:
        status_str = "Connection Failed";
        break;
      case NetWizardConnectionStatus::CONNECTION_LOST:
        status_str = "Connection Lost";
        break;
      case NetWizardConnectionStatus::NOT_FOUND:
        status_str = "Not Found";
        break;
      default:
        status_str = "Unknown";
    }

    Serial.printf("NW connection status changed: %s\n", status_str.c_str());
    if (status == NetWizardConnectionStatus::CONNECTED) {
      // Local IP
      Serial.printf("Local IP: %s\n", NW.localIP().toString().c_str());
      // Gateway IP
      Serial.printf("Gateway IP: %s\n", NW.gatewayIP().toString().c_str());
      // Subnet mask
      Serial.printf("Subnet mask: %s\n", NW.subnetMask().toString().c_str());
    }
  });

  // Listen for portal state changes
  NW.onPortalState([](NetWizardPortalState state) {
    String state_str = "";

    switch (state) {
      case NetWizardPortalState::IDLE:
        state_str = "Idle";
        break;
      case NetWizardPortalState::CONNECTING_WIFI:
        state_str = "Connecting to WiFi";
        break;
      case NetWizardPortalState::WAITING_FOR_CONNECTION:
        state_str = "Waiting for Connection";
        break;
      case NetWizardPortalState::SUCCESS:
        state_str = "Success";
        break;
      case NetWizardPortalState::FAILED:
        state_str = "Failed";
        break;
      case NetWizardPortalState::TIMEOUT:
        state_str = "Timeout";
        break;
      default:
        state_str = "Unknown";
    }

    Serial.printf("NW portal state changed: %s\n", state_str.c_str());
  });

  NW.onConfig([&]() {
    Serial.println("NW onConfig Received");
    return true; // <-- return true to approve request, false to reject
  });

  // Start NetWizard
  Serial.println("starting autoConnect");
  NW.autoConnect("COOPFEEDER", "");
  
  // Check if configured
  if (NW.isConfigured()) {
    Serial.println("Device is configured");
  } else {
    Serial.println("Device is not configured");
  }

  // Start WebServer
  server.begin();
  return true;
}

// reset wifi (after double reset detected)
void resetWifi() {
  // Clear WiFi settings from preferences directly instead of using NW.reset()
  // This avoids the "STA not started" error that occurs when NW.reset() is called
  // before WiFi is properly initialized
  NW.erase();
  NW.autoConnect("COOPFEEDER", "");
  preferences.putBool("DRD", false);

  // Log the action
  log::toAll("WiFi settings cleared, restarting device...");
  
  // Small delay to ensure log message is sent
  //delay(1000);
  
  // Restart the ESP32
  //ESP.restart();
}

// Debounce WiFi checks — transient disconnects shouldn't trigger reconnects
static unsigned long lastWifiDisconnect = 0;
static int wifiFailCount = 0;

void wifiCheck() {
  if (WiFi.status() == WL_CONNECTED) {
    wifiFailCount = 0;
    return;
  }
  
  // First disconnect: just note the time, don't react yet
  if (wifiFailCount == 0) {
    lastWifiDisconnect = millis();
    wifiFailCount = 1;
    return;
  }
  
  // Wait 5 seconds before deciding it's a real disconnect
  if (millis() - lastWifiDisconnect < 5000) {
    return;
  }
  
  // Still disconnected after 5s — try a soft reconnect
  if (wifiFailCount < 3) {
    wifiFailCount++;
    Serial.printf("WiFi disconnected, attempt %d...\n", wifiFailCount);
    WiFi.reconnect();
    lastWifiDisconnect = millis();
    return;
  }
  
  // Multiple soft reconnects failed — do a full reconnect via NetWizard
  Serial.println("WiFi reconnect failed, restarting autoConnect...");
  wifiFailCount = 0;
  WiFi.disconnect(true);
  delay(100);
  NW.autoConnect("COOPFEEDER", "");
}
#endif

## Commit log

2026-09-12 added update button
2026-09-26 added openscad case
    [base.stl, electronics_fit.scad, lid.stl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]
